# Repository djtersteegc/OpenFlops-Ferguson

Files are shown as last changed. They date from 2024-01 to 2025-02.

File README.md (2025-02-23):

This is a respin of [SukkoPera's](https://github.com/SukkoPera) original [OpenFlops](https://github.com/SukkoPera/OpenFlops) project to create a custom version that plugs directly into the male 50 pin disk header of my [Ferguson Big Board](https://github.com/djtersteegc/Ferguson-Big-Board-Reproduction) SBC Z80 computer.  Changes from the original version include:

- Updated to KiCad 7.x
- Switched from USB to Micro SD for image storage
- Switched to 74LS07's for buffers
- Interface is a now a 50 pin connector and PCB laid out specifically for the Ferguson use case

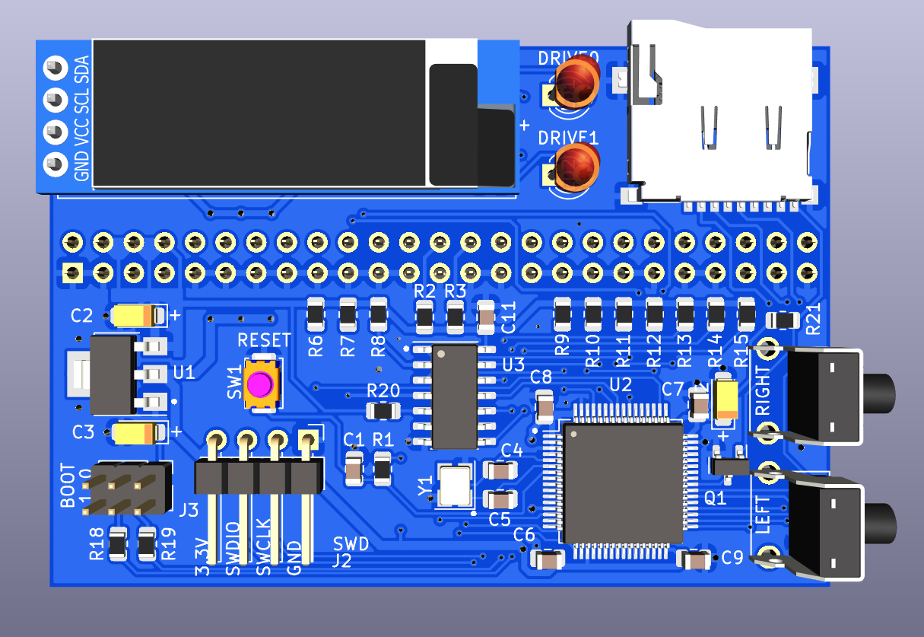
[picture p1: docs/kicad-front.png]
kicad-front


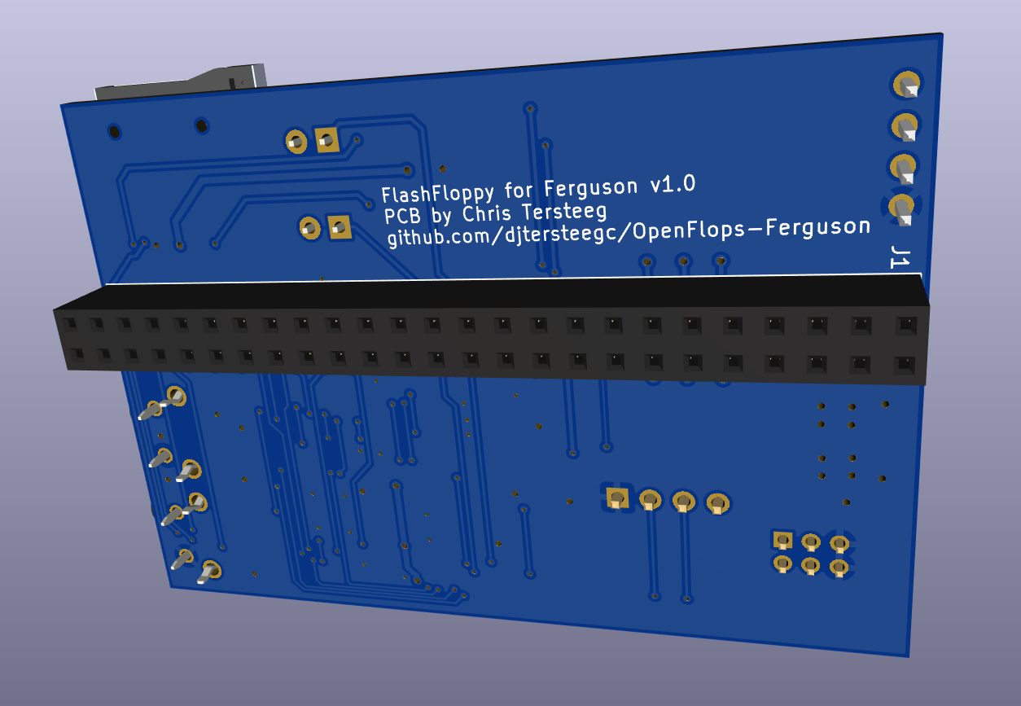
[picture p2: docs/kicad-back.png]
kicad-back


Version 1.1 shrinks the SWD pin headers to allow room for a 9mm speaker to make floppy'ish sounds when accessing and seeking.

https://youtu.be/Bbqj_xtnAqc

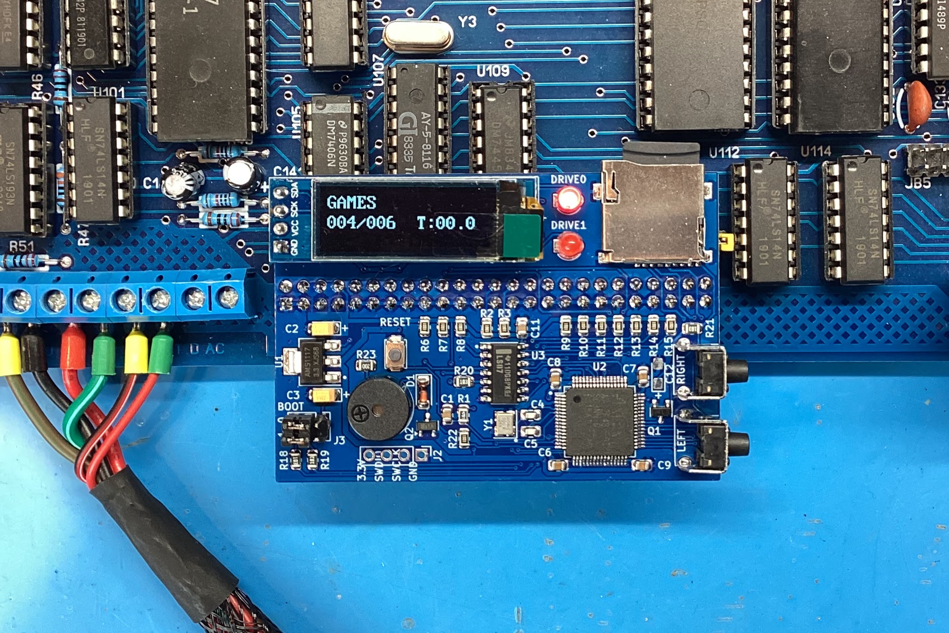
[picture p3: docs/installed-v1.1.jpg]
installed


Schematic v1.0 - https://djtersteegc.github.io/OpenFlops-Ferguson/OpenFlops-Ferguson-Schematic-v1.0.pdf

Schematic v1.1 - https://djtersteegc.github.io/OpenFlops-Ferguson/OpenFlops-Ferguson-Schematic-v1.1.pdf

### BOM

Interactive v1.0 - [https://djtersteegc.github.io/OpenFlops-Ferguson/ibom-v1.0.html](https://djtersteegc.github.io/OpenFlops-Ferguson/ibom-v1.0.html)

CSV v1.0 - [https://djtersteegc.github.io/OpenFlops-Ferguson/OpenFlops-Ferguson-BOM-v1.0.csv](https://djtersteegc.github.io/OpenFlops-Ferguson/OpenFlops-Ferguson-BOM-v1.0.csv)

Interactive v1.1 - [https://djtersteegc.github.io/OpenFlops-Ferguson/ibom-v1.1.html](https://djtersteegc.github.io/OpenFlops-Ferguson/ibom-v1.1.html)

CSV v1.1 - [https://djtersteegc.github.io/OpenFlops-Ferguson/OpenFlops-Ferguson-BOM-v1.1.csv](https://djtersteegc.github.io/OpenFlops-Ferguson/OpenFlops-Ferguson-BOM-v1.1.csv)

For the MCU I switched from the STM32F105RBT6 to the Artery AT32F435RGT7 which is now well supported by FlashFloppy and a more capable chip for potential future expansion (dual drives?). You could also build with the STM32F105RBT6 and use the appropiate STM programmer and FlashFloppy firmware version.

C12 is a extra bulk capacitor footprint I added near the MCU in case it was needed.  I've run mine without and seems fine, so can be considered optional.  Measured current draw on the board is around 100ma, with the OLED display active.

### Assembly

Do all the SMD components first using your favorite method.  I tried the Proto-Advantage PA0096-S TQFP-64 stencil for the MCU since I didn't have another one anywhere and was to cheap to get a proper stencil from JLCPCB, but unfortunately the pads are 2mm in length on that guy which result in excessive solder paste being applied to the board and then general sadness and bridging after it reflows.

I would flash the MCU (see below) next either by soldering on the angle headers for the SWD port or just holding headers in the holes to ensure everything works before doing the rest of the through hole components since it's a whole lot easier to do rework if needed with nothing else on the board.

Once all flashed and assembled, the normal jumper settings for the BOOT0 and BOOT1 pins are to the left (connected to GND).  BOOT1 really isn't even needed, but I added it just in case.

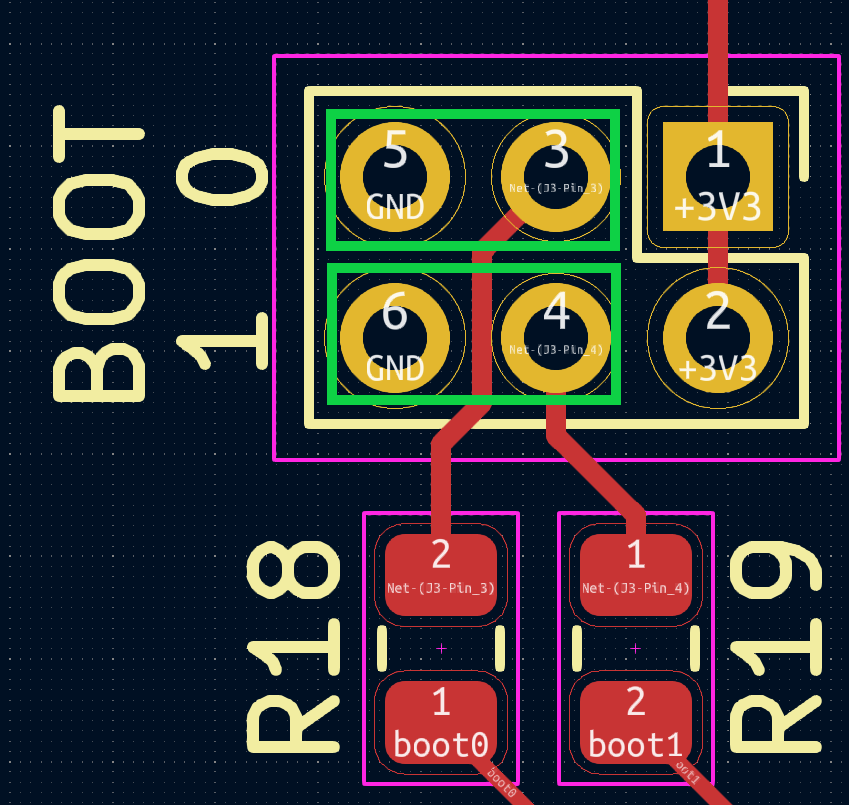
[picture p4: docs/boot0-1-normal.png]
boot0-1-normal


### Firmware Flashing

To flash the FlashFloppy firmware on the MCU, I used Arterty's AT-Link+ hooked up the SWD port on the board.

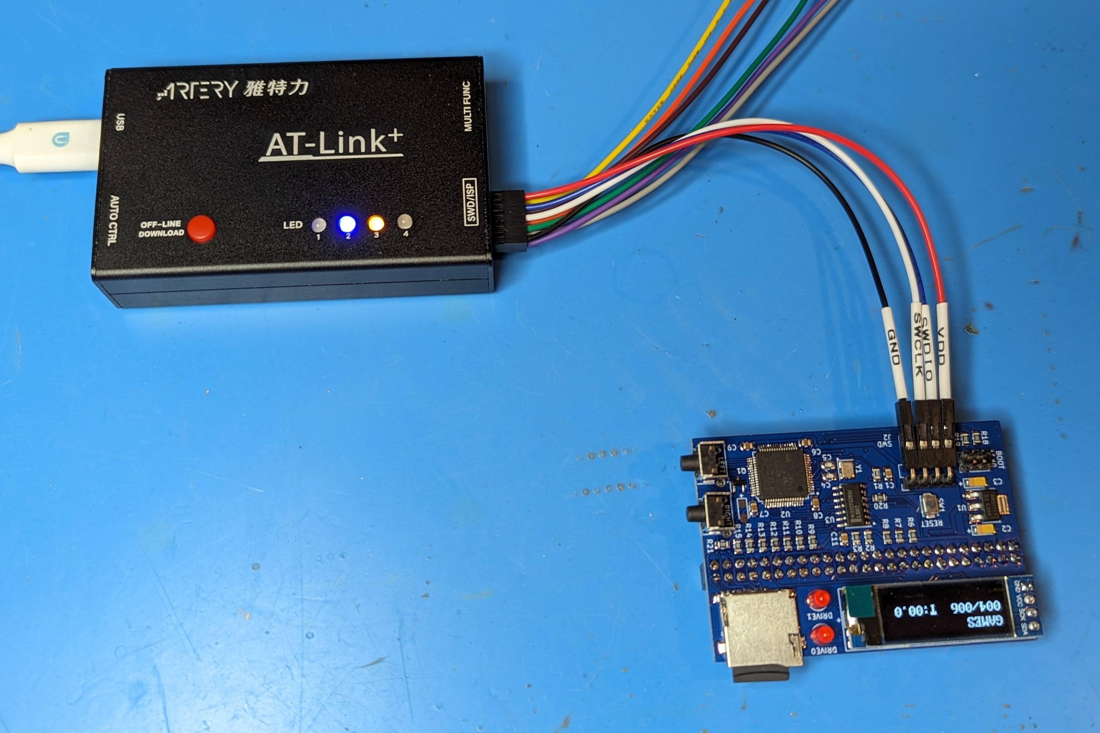
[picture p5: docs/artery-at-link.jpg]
artery-at-link


For the v1.1 boards, a pogo pin clamp is handy.

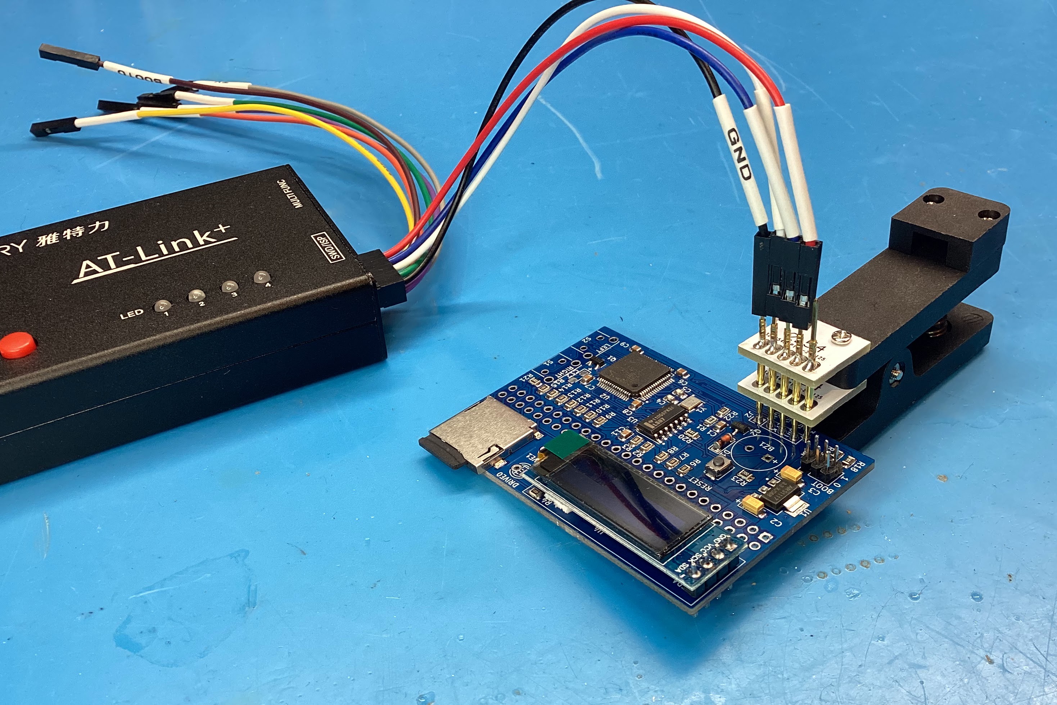
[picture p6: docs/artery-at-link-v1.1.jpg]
artery-at-link


If your MCU is blank, you should be able to connect without having to set the BOOT0 jumper to high (3.3V)  If not and it is already running a user flashed program, you will need to move BOOT0 to the right in order for the bootloader to run and you can connect for flashing.

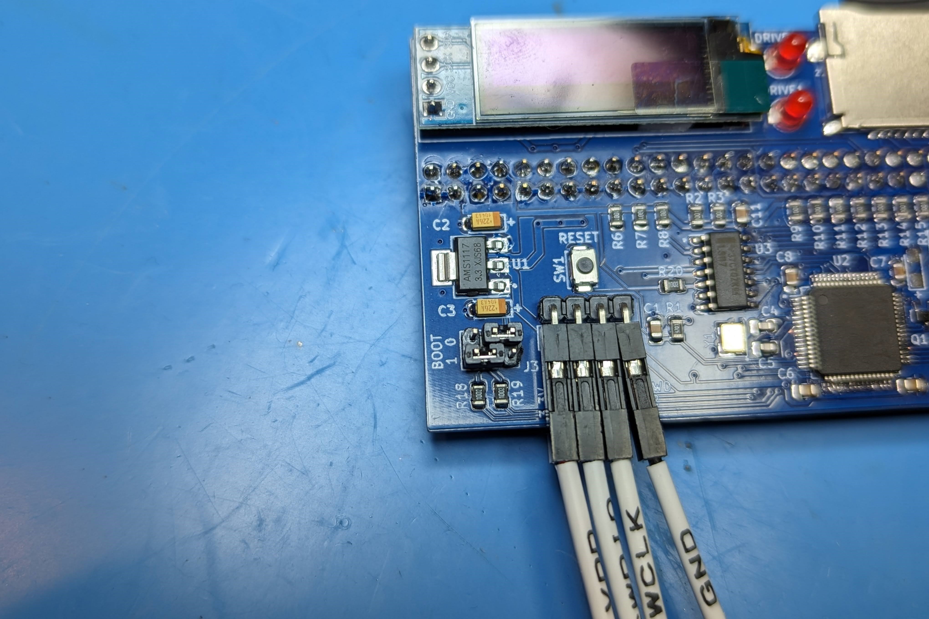
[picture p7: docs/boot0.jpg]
boot0


Using Artery's ICP Programmer, **Connect** to the MCU and load the appropiate FlashFloppy hex file via the **Add** button and then hit **DownLoad**.

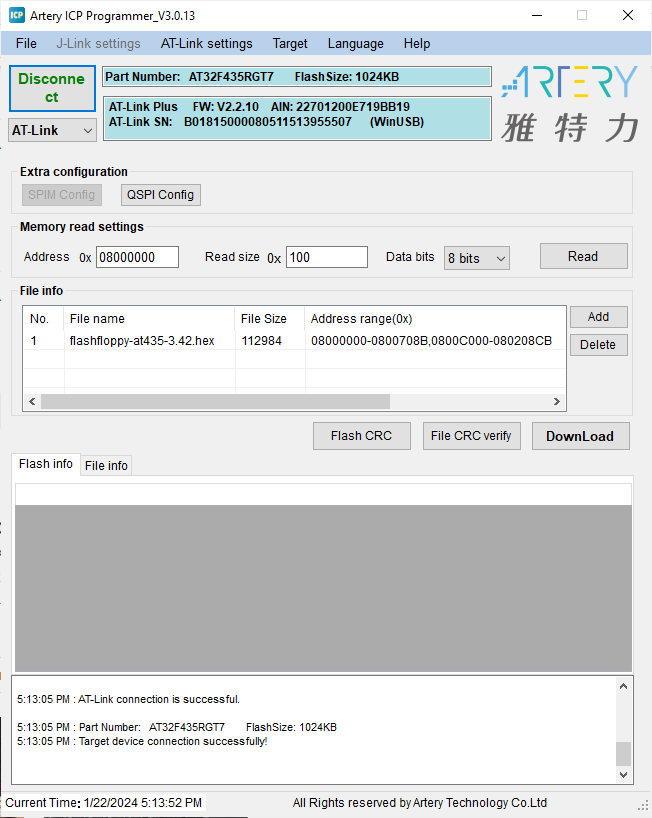
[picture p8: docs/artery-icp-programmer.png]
artery-icp-programmer


Move the BOOT0 jumper back to the left (GND, logical 0) if needed and once you repower, the OLED should display FlashFloppy+. 

### Usage

If you have v1.0 repoduction board (or original), you will need to add a bodge wire to pull 5V power from the resistor network to either pin 4, 6, or 8 (or all three) since the FlashFloppy board is powered directly from normally unused pins on the Ferguson's floppy port.

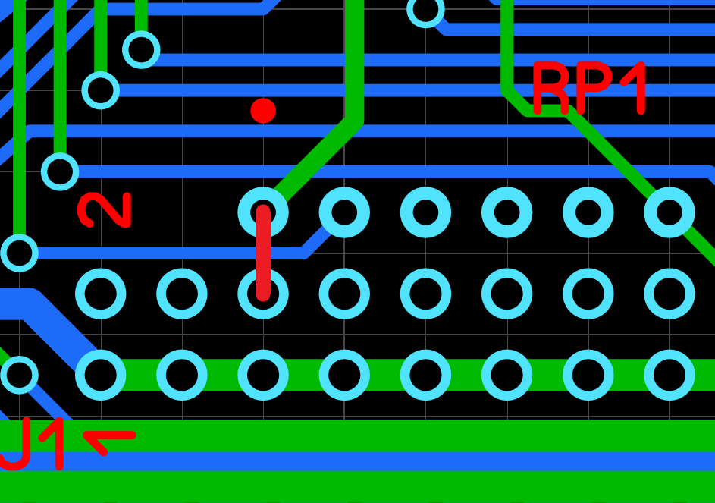
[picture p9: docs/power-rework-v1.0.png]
power-rework-v1.0


If you have a version 1.1 board, simply close the solder jumper on the back of the board to do the same.

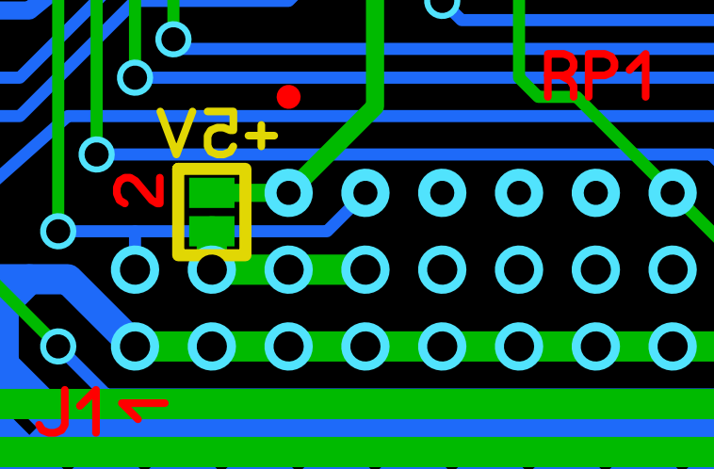
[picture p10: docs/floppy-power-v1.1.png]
floppy-power-v1.1


Plug into your Ferguson and enjoy a clutter free floppy experience. ;)

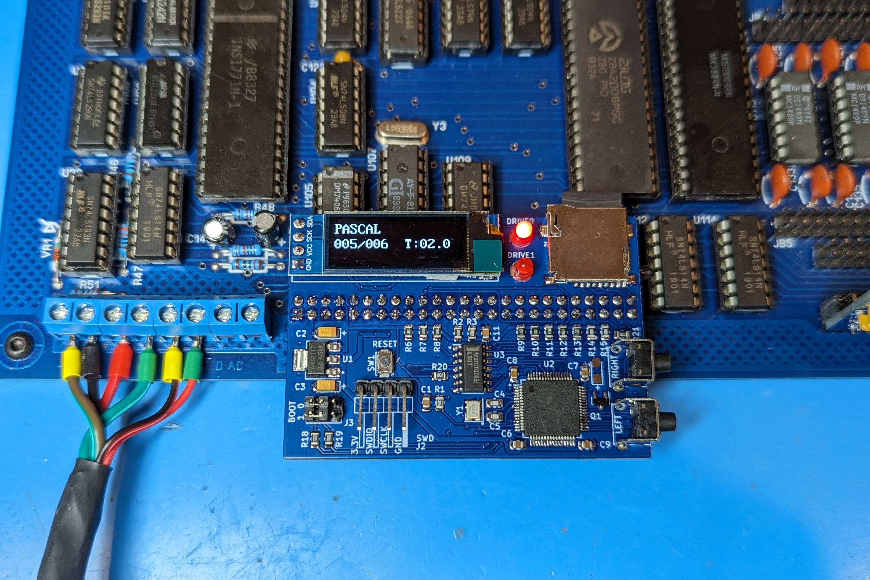
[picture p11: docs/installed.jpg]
installed


### Versions

**v1.0** - Initial release, tested and working.

**v1.1** - Shrinks the SWD pin headers to allow room for a 9mm speaker.

### Getting a Board

If you're in the US, hit me up on this VCFed thread and if I have any extras, can drop one in the mail for a couple bucks.  

https://forum.vcfed.org/index.php?threads/recreating-the-ferguson-big-board.68349/

Otherwise [gerbers](gerbers) are available for use at your favorite PCB fab. 

### License

The OpenFlops documentation, including the design itself, is copyright &copy; SukkoPera 2019-2020.

OpenFlops is Open Hardware licensed under the [CERN OHL v. 1.2](http://ohwr.org/cernohl).

You may redistribute and modify this documentation under the terms of the CERN OHL v.1.2. This documentation is distributed *as is* and WITHOUT ANY EXPRESS OR IMPLIED WARRANTIES whatsoever with respect to its functionality, operability or use, including, without limitation, any implied warranties OF MERCHANTABILITY, SATISFACTORY QUALITY, FITNESS FOR A PARTICULAR PURPOSE or infringement. We expressly disclaim any liability whatsoever for any direct, indirect, consequential, incidental or special damages, including, without limitation, lost revenues, lost profits, losses resulting from business interruption or loss of data, regardless of the form of action or legal theory under which the liability may be asserted, even if advised of the possibility or likelihood of such damages.

A copy of the full license is included in file [LICENSE.pdf](LICENSE.pdf), please refer to it for applicable conditions. In order to properly deal with its terms, please see file [LICENSE_HOWTO.pdf](LICENSE_HOWTO.pdf).

The contact points for information about manufactured Products (see section 4.2) are listed in file [PRODUCT.md](PRODUCT.md).

Any modifications made by Licensees (see section 3.4.b) shall be recorded in file [CHANGES.md](CHANGES.md).

The Documentation Location of the original project is https://github.com/SukkoPera/OpenFlops/.

### Thanks
- SukkoPera for the [OpenFlops](https://github.com/SukkoPera/OpenFlops) project
- H.M for publishing the [original Gotek schematics](docs/gotek_usb-fde_block-diagram.jpg)
- [keirf](https://github.com/keirf) for FlashFloppy

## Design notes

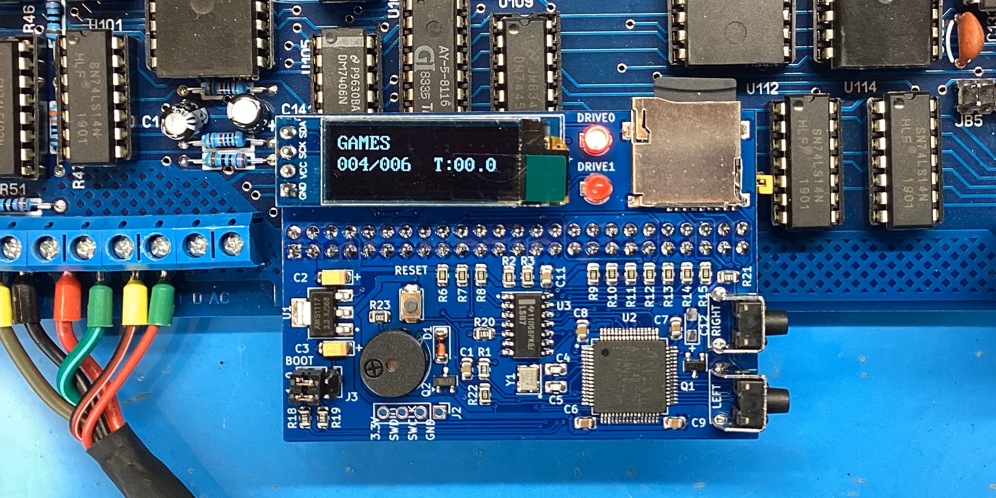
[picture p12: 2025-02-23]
docs/social.jpg

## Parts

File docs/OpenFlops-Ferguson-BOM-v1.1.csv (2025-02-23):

Reference | Value | Datasheet | Footprint | Qty | DNP
BZ1 | Buzzer | ~ | Buzzer_Beeper:MagneticBuzzer_PUI_AT-0927-TT-6-R | 1
C1,C6,C7,C8,C9,C11 | 100n | ~ | Capacitor_SMD:C_0805_2012Metric | 6
C2,C3,C12 | 22uf | ~ | Capacitor_Tantalum_SMD:CP_EIA-3216-12_Kemet-S_Pad1.58x1.35mm_HandSolder | 3
C4,C5 | 22p | ~ | Capacitor_SMD:C_0805_2012Metric | 2
C10 | 47uf | ~ | Capacitor_Tantalum_SMD:CP_EIA-3528-12_Kemet-T_Pad1.50x2.35mm_HandSolder | 1
D1 | LL4148 | http://www.vishay.com/docs/85557/ll4148.pdf | Diode_SMD:D_MiniMELF | 1
J1 | Conn_02x25_Odd_Even | ~ | Connector_PinSocket_2.54mm:PinSocket_2x25_P2.54mm_Vertical | 1
J2 | SWD | ~ | Connector_PinHeader_2.54mm:PinHeader_1x04_P2.54mm_Vertical | 1
J3 | BOOT 1/0 | ~ | Connector_PinHeader_2.00mm:PinHeader_2x03_P2.00mm_Vertical | 1
LD1 | DRIVE0 | ~ | LED_THT:LED_D3.0mm | 1
LD2 | DRIVE1 | ~ | LED_THT:LED_D3.0mm | 1
P1 | ST-TF-003A |  | ST-TF-003A:SUNTECH_ST-TF-003A | 1
Q1 | BSS138 | https://www.onsemi.com/pub/Collateral/BSS138-D.PDF | Package_TO_SOT_SMD:SOT-23 | 1
Q2 | MMBT3904 | https://www.onsemi.com/pdf/datasheet/pzt3904-d.pdf | Package_TO_SOT_SMD:SOT-23 | 1
R1 | 4k7 | ~ | Resistor_SMD:R_0805_2012Metric | 1
R2,R3,R4,R5 | 1k | ~ | Resistor_SMD:R_0805_2012Metric | 4
R6,R7,R8,R9,R10,R11,R12,R13,R14,R15,R22 | 1K | ~ | Resistor_SMD:R_0805_2012Metric | 11
R16,R17,R18,R19,R20,R21 | 10K | ~ | Resistor_SMD:R_0805_2012Metric | 6
R23 | 22 | ~ | Resistor_SMD:R_0805_2012Metric | 1
S1 | RIGHT | ~ | OpenFlops:PUSH_BUTTON_RIGHT_ANGLE | 1
S2 | LEFT | ~ | OpenFlops:PUSH_BUTTON_RIGHT_ANGLE | 1
SW1 | RESET | ~ | Button_Switch_SMD:SW_Push_SPST_NO_Alps_SKRK | 1
U1 | LM1117-3.3 | http://www.ti.com/lit/ds/symlink/lm1117.pdf | Package_TO_SOT_SMD:SOT-223-3_TabPin2 | 1
U2 | AT32F435RGT7 | http://www.st.com/st-web-ui/static/active/en/resource/technical/document/datasheet/CD00220364.pdf | Package_QFP:LQFP-64_10x10mm_P0.5mm | 1
U3 | 74LS07 | www.ti.com/lit/ds/symlink/sn74ls07.pdf | Package_SO:SOIC-14_3.9x8.7mm_P1.27mm | 1
U4 | OLED-0.91-128x32 |  | Tersteeg:OLED-0.91-128x32 | 1
Y1 | 8MHz | ~ | Crystal:Crystal_SMD_Abracon_ABM8G-4Pin_3.2x2.5mm | 1

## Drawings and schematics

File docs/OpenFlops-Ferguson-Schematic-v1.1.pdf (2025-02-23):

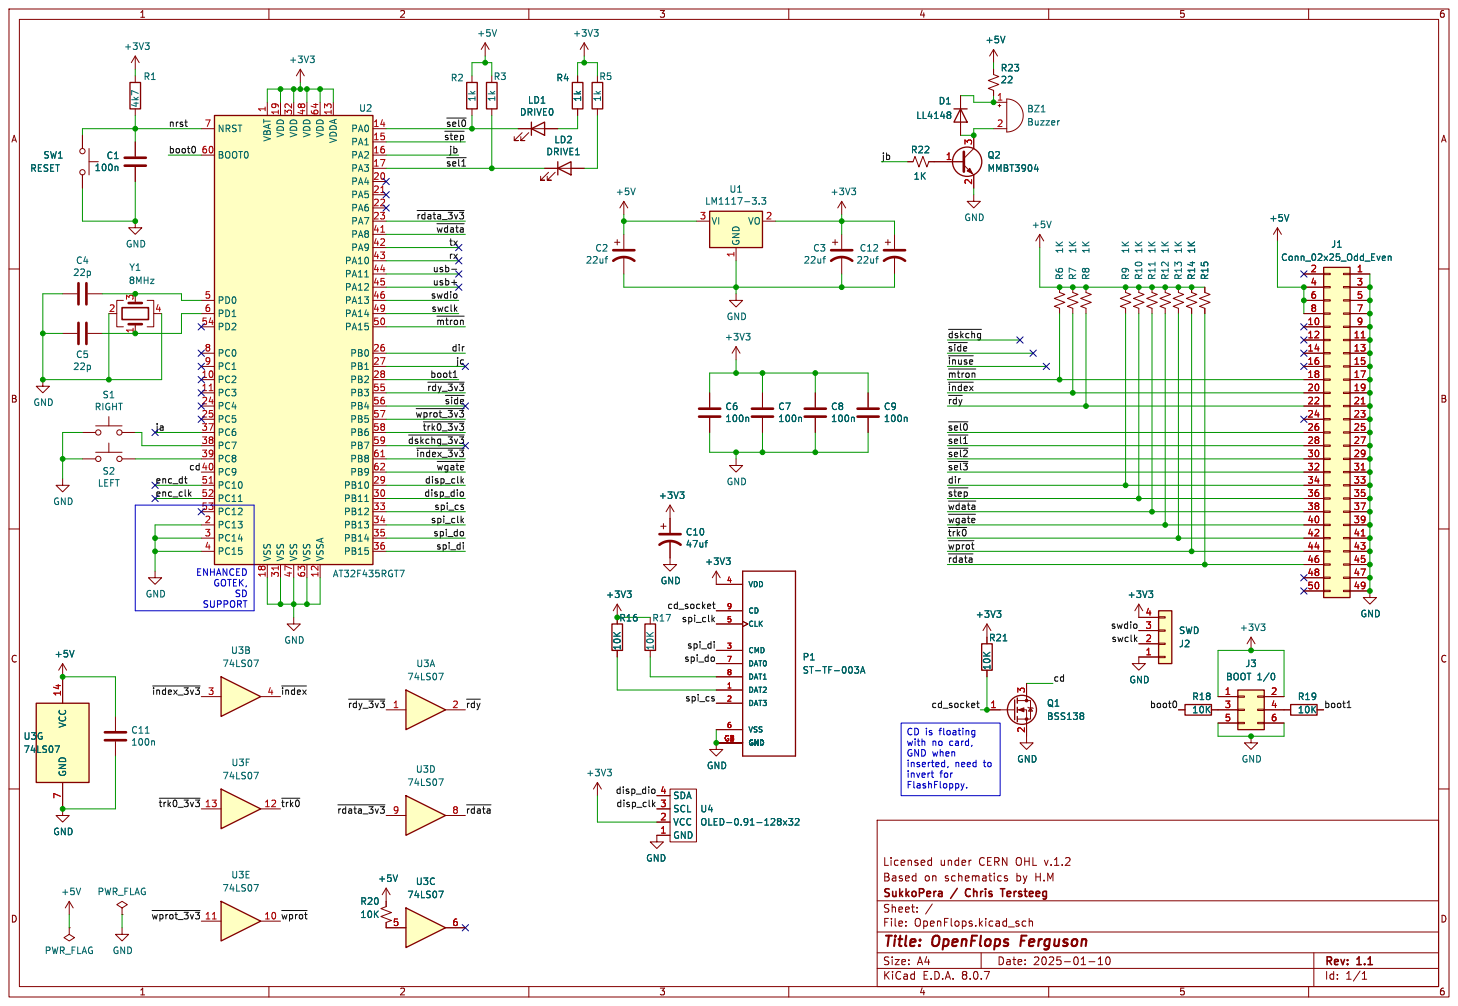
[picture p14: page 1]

1 PC2 10 PC3 11 VSSA 12 VDDA 13 PA0 14 PA1 15 PA2 16 PA3 17 VSS 18 VDD 19 PC13 2 PA4 20 PA5 21 PA6 22 PA7 23 PC4 24 PC5 25 PB0 26 PB1 27 PB2 28 PB10 29 PC14 3 PB11 30 VSS 31 VDD 32 PB12 33 PB13 34 PB14 35 PB15 36 PC6 37 PC7 38 PC8 39 PC15 4 PC9 40 PA8 41 PA9 42 PA10 43 PA11 44 PA12 45 PA13 46 VSS 47 VDD 48 PA14 49 PD0 5 PA15 50 PC10 51 PC11 52 PC12 53 PD2 54 PB3 55 PB4 56 PB5 57 PB6 58 PB7 59 PD1 6 BOOT0 60 PB8 61 PB9 62 VSS 63 VDD 64 NRST 7 PC0 8 PC1 9 U2 AT32F435RGT7 GND 1 VCC 2 SCL 3 SDA 4 U4 OLED-0.91-128x32 C6
nrst

U4 OLED-0.91-128x32 GND 1 VCC 2 SCL 3 SDA 4

Id: 1/1 Title: OpenFlops Ferguson

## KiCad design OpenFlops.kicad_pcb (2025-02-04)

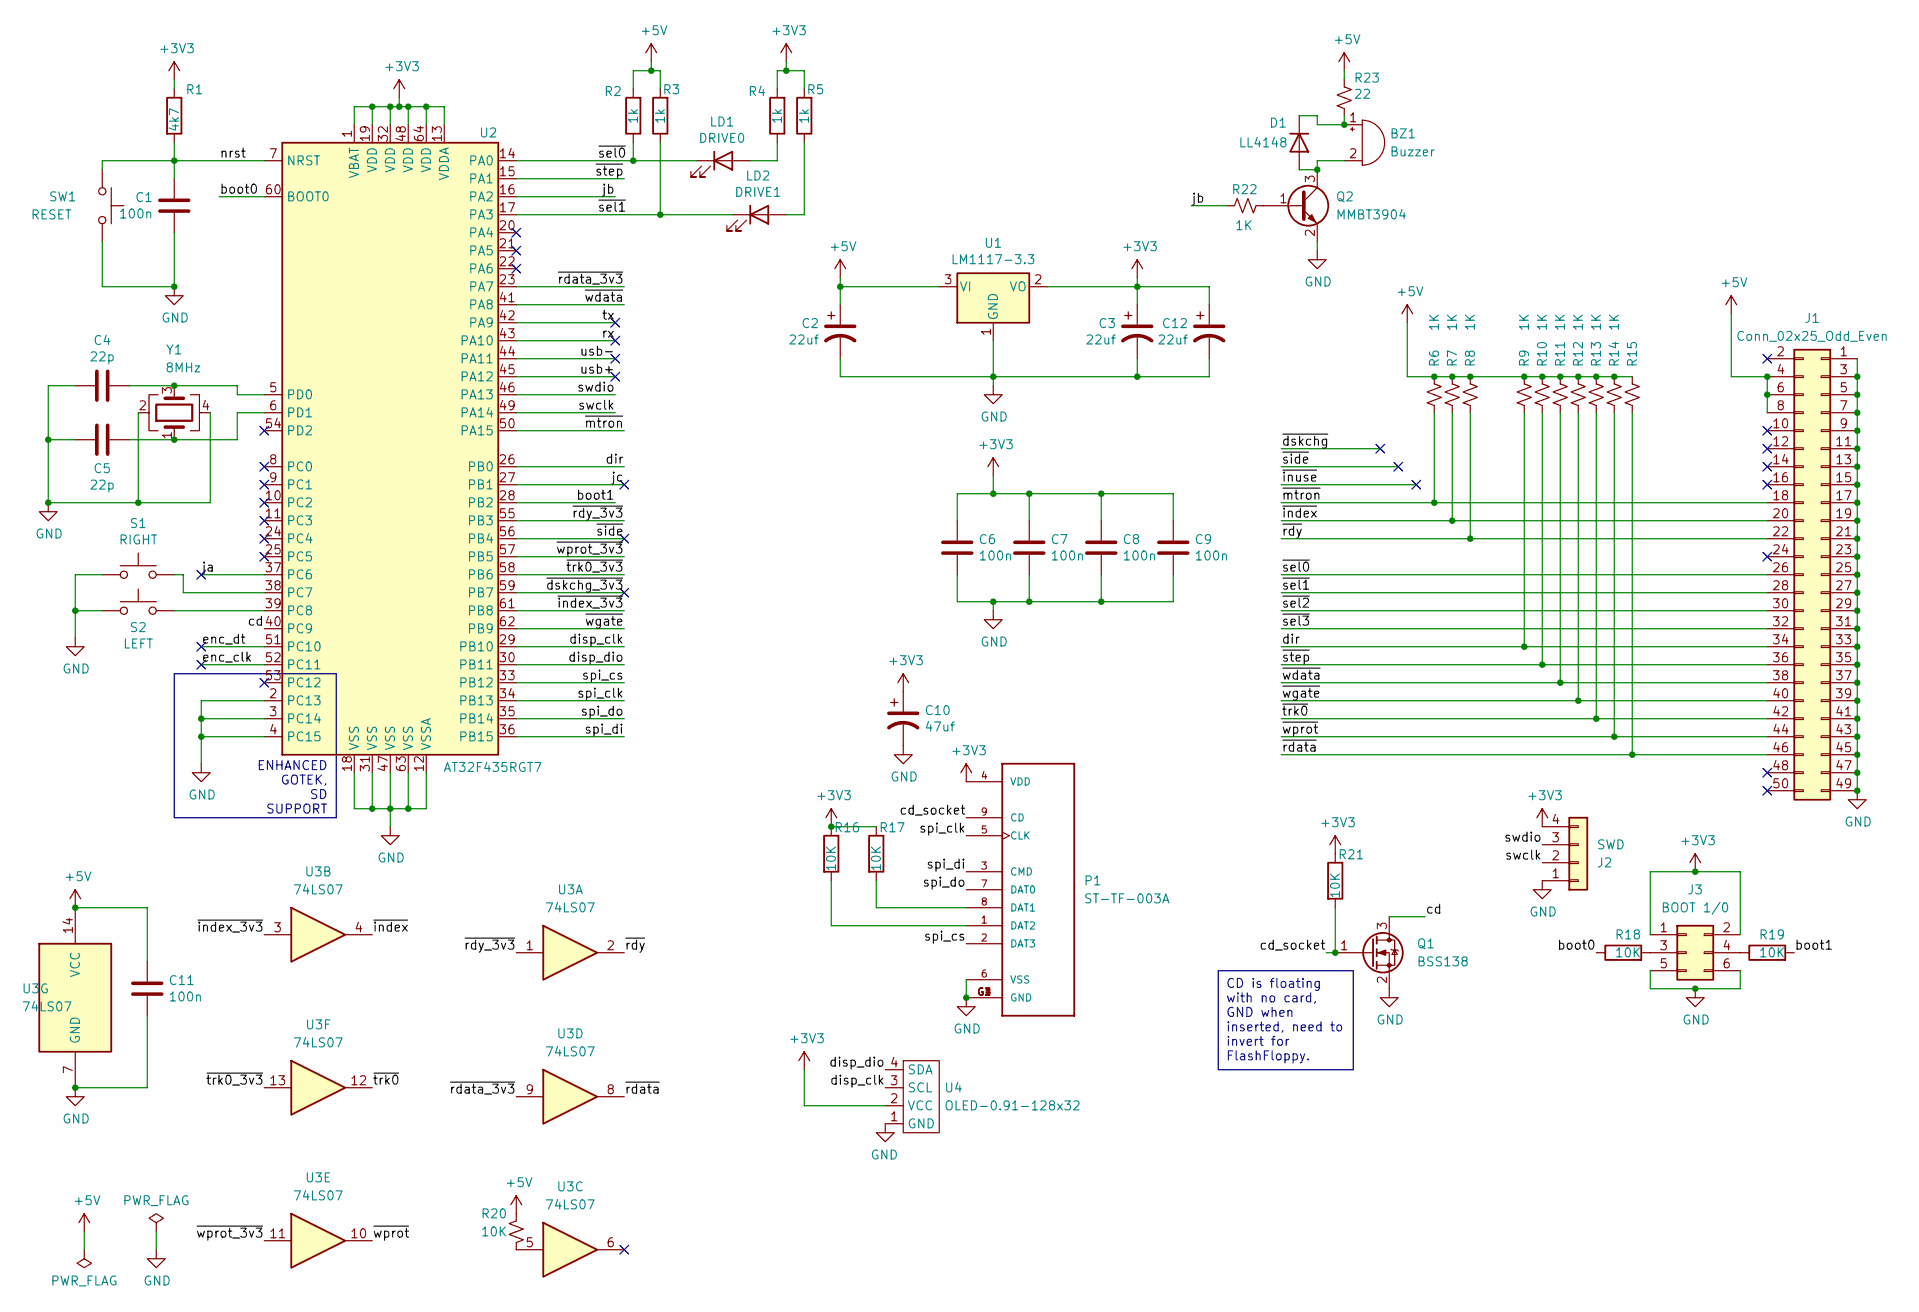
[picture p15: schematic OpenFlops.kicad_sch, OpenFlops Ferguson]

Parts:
BZ1: Buzzer; MagneticBuzzer_PUI_AT-0927-TT-6-R
C1, C6, C7, C8, C9, C11: 100n; C_0805_2012Metric; MFG Part Num MULTILAYER CERAMIC CAPACITORS MLCC - SM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; JLCPCB PN CC0805KRX7R9BB104
C2, C3, C12: 22uf; CP_EIA-3216-12_Kemet-S_Pad1.58x1.35mm_HandSolder
C4, C5: 22p; C_0805_2012Metric; MFG Part Num MULTILAYER CERAMIC CAPACITORS MLCC - SM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; JLCPCB PN CL21C220JBANNNC
C10: 47uf; CP_EIA-3528-12_Kemet-T_Pad1.50x2.35mm_HandSolder
D1: LL4148; D_MiniMELF
J1: Conn_02x25_Odd_Even; PinSocket_2x25_P2.54mm_Vertical
J2: SWD; PinHeader_1x04_P2.54mm_Vertical
J3: BOOT 1/0; PinHeader_2x03_P2.00mm_Vertical
LD1: DRIVE0; LED_D3.0mm
LD2: DRIVE1; LED_D3.0mm
P1: ST-TF-003A; SUNTECH_ST-TF-003A
Q1: BSS138; SOT-23
Q2: MMBT3904; SOT-23
R1: 4k7; R_0805_2012Metric; MFG Part Num CHIP RESISTOR - SURFACE MOUNT 4.7KOHMS 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; JLCPCB PN 0805W8F4701T5E
R2, R3: 1k; R_0805_2012Metric; MFG Part Num CHIP RESISTOR - SURFACE MOUNT 1KOHMS ±1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; JLCPCB PN 0805W8F1001T5E
R4, R5: 1k; R_0805_2012Metric
R6, R7, R8, R9, R10, R11, R12, R13, R14, R15, R22: 1K; R_0805_2012Metric
R16, R17, R18, R19, R21: 10K; R_0805_2012Metric; MFG Part Num CHIP RESISTOR - SURFACE MOUNT 4.7KOHMS 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; JLCPCB PN 0805W8F4701T5E
R20: 10K; R_0805_2012Metric
R23: 22; R_0805_2012Metric
S1: RIGHT; PUSH_BUTTON_RIGHT_ANGLE
S2: LEFT; PUSH_BUTTON_RIGHT_ANGLE
SW1: RESET; SW_Push_SPST_NO_Alps_SKRK
U1: LM1117-3.3; SOT-223-3_TabPin2; MFG Part Num LOW DROPOUT REGULATORS(LDO) POSITIVE FI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; JLCPCB PN AMS1117-3.3
U2: AT32F435RGT7; LQFP-64_10x10mm_P0.5mm; MFG Part Num ST MICROELECTRONICS LQFP-64_10X10X05P R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; JLCPCB PN STM32F105RBT6
U3: 74LS07; SOIC-14_3.9x8.7mm_P1.27mm
U4: OLED-0.91-128x32
Y1: 8MHz; Crystal_SMD_Abracon_ABM8G-4Pin_3.2x2.5mm

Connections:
+3V3: C3.1, C6.1, C7.1, C8.1, C9.1, C10.1, C12.1, J2.4, J3.1, J3.2, P1.4 (VDD), R1.1, R4.2, R5.2, R16.1, R17.1, R21.1, U1.2 (VO), U2.1 (VBAT), U2.13 (VDDA), U2.19 (VDD), U2.32 (VDD), U2.48 (VDD), U2.64 (VDD), U4.2 (VCC)
+5V: C2.1, C11.1, J1.4, J1.6, J1.8, R2.2, R3.2, R6.1, R7.1, R8.1, R9.1, R10.1, R11.1, R12.1, R13.1, R14.1, R15.1, R20.1, R23.1, U1.3 (VI), U3.14 (VCC)
/boot0: R18.1, U2.60 (BOOT0)
/boot1: R19.2, U2.28 (PB2)
/cd: Q1.3 (D), U2.40 (PC9)
/cd_socket: P1.9 (CD), Q1.1 (G), R21.2
/dir: J1.34, R9.2, U2.26 (PB0)
/disp_clk: U2.29 (PB10), U4.3 (SCL)
/disp_dio: U2.30 (PB11), U4.4 (SDA)
/enc_clk: U2.52 (PC11)
/enc_dt: U2.51 (PC10)
/ja: U2.37 (PC6)
/jb: R22.2, U2.16 (PA2)
/jc: U2.27 (PB1)
/nrst: C1.1, R1.2, SW1.1, U2.7 (NRST)
/rx: U2.43 (PA10)
/spi_clk: P1.5 (CLK), U2.34 (PB13)
/spi_cs: P1.2 (DAT3), U2.33 (PB12)
/spi_di: P1.3 (CMD), U2.36 (PB15)
/spi_do: P1.7 (DAT0), U2.35 (PB14)
/swclk: J2.2, U2.49 (PA14)
/swdio: J2.3, U2.46 (PA13)
/tx: U2.42 (PA9)
/usb+: U2.45 (PA12)
/usb-: U2.44 (PA11)
/~dskchg_3v3: U2.59 (PB7)
/~index_3v3: U2.61 (PB8), U3.3
/~index: J1.20, R7.2, U3.4
/~mtron: J1.18, R6.2, U2.50 (PA15)
/~rdata_3v3: U2.23 (PA7), U3.9
/~rdata: J1.46, R15.2, U3.8
/~rdy_3v3: U2.55 (PB3), U3.1
/~rdy: J1.22, R8.2, U3.2
/~sel0: J1.26, LD1.1 (K), R2.1, U2.14 (PA0)
/~sel1: J1.28, LD2.1 (K), R3.1, U2.17 (PA3)
/~sel2: J1.30
/~sel3: J1.32
/~side: U2.56 (PB4)
/~step: J1.36, R10.2, U2.15 (PA1)
/~trk0_3v3: U2.58 (PB6), U3.13
/~trk0: J1.42, R13.2, U3.12
/~wdata: J1.38, R11.2, U2.41 (PA8)
/~wgate: J1.40, R12.2, U2.62 (PB9)
/~wprot_3v3: U2.57 (PB5), U3.11
/~wprot: J1.44, R14.2, U3.10
GND: C1.2, C2.2, C3.2, C4.2, C5.2, C6.2, C7.2, C8.2, C9.2, C10.2, C11.2, C12.2, J1.1, J1.3, J1.5, J1.7, J1.9, J1.11, J1.13, J1.15, J1.17, J1.19, J1.21, J1.23, J1.25, J1.27, J1.29, J1.31, J1.33, J1.35, J1.37, J1.39, J1.41, J1.43, J1.45, J1.47, J1.49, J2.1, J3.5, J3.6, P1.6 (VSS), P1.G1 (GND), P1.G2 (GND), P1.G3 (GND), P1.G4 (GND), Q1.2 (S), Q2.2 (E), S1.1, S2.1, SW1.2, U1.1 (GND), U2.2 (PC13), U2.3 (PC14), U2.4 (PC15), U2.12 (VSSA), U2.18 (VSS), U2.31 (VSS), U2.47 (VSS), U2.63 (VSS), U3.7 (GND), U4.1 (GND), Y1.2, Y1.4
unnamed: BZ1.1 (+), D1.1 (K), R23.2
unnamed: BZ1.2 (-), D1.2 (A), Q2.3 (C)
unnamed: J3.3, R18.2
unnamed: J3.4, R19.1
unnamed: LD1.2 (A), R4.1
unnamed: LD2.2 (A), R5.1
unnamed: P1.8 (DAT1), R17.2
unnamed: P1.1 (DAT2), R16.2
unnamed: Q2.1 (B), R22.1
unnamed: R20.2, U3.5
unnamed: S1.2, U2.38 (PC7)
unnamed: S2.2, U2.39 (PC8)
unnamed: C4.1, U2.5 (PD0), Y1.3
unnamed: C5.1, U2.6 (PD1), Y1.1

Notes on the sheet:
CD is floating with no card, GND when inserted, need to invert for FlashFloppy.
ENHANCED GOTEK, SD SUPPORT

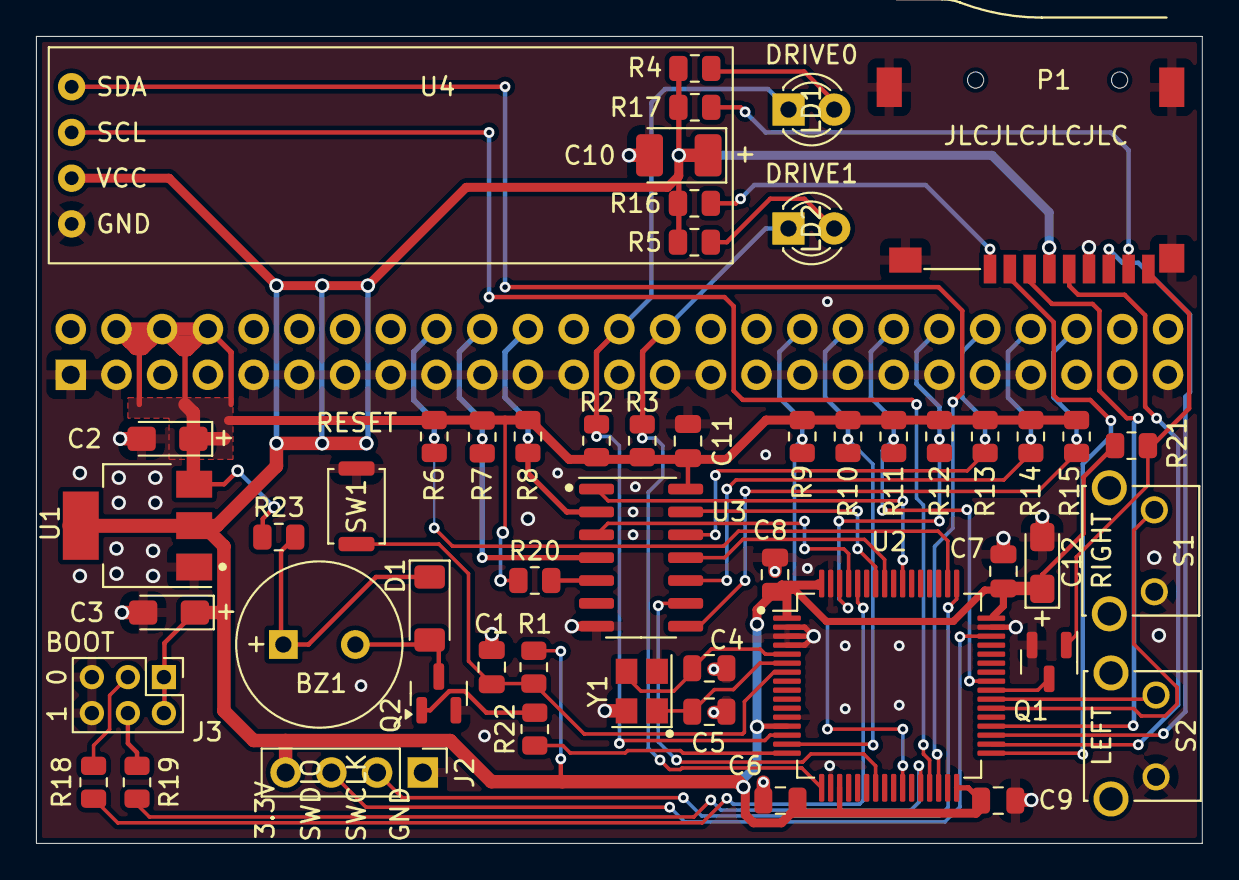
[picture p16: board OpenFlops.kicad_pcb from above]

Board: 2 copper layers, 64.8 x 44.8 mm, 53 parts (1 on the bottom side), 48 nets.

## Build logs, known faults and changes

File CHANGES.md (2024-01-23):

## CHANGES

Any modifications to the OpenFlops design and documentation made by any Licensee MUST be noted in this file, as per *section 3.4.b* of the [license](LICENSE.pdf).

### 2024-01-22 - Chris Tersteeg
Revamp design to plug into directly to a Ferguson Big Board SBC

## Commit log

2024-01-23 Restructure for v1.0 or the Ferguson version
    [OpenFlops-B_Cu.gbr, OpenFlops-B_Mask.gbr, OpenFlops-B_Paste.gbr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]
2025-02-04 Update to v1.1
    [OpenFlops-B_Cu.gbr, OpenFlops-B_Mask.gbr, OpenFlops-B_Paste.gbr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]
2025-02-23 Add v1.1 schematic and CSV BOM
    [OpenFlops-Ferguson-BOM-v1.1.csv]
2025-02-23 Fix Schematic PDF

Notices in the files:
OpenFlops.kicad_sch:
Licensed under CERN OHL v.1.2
